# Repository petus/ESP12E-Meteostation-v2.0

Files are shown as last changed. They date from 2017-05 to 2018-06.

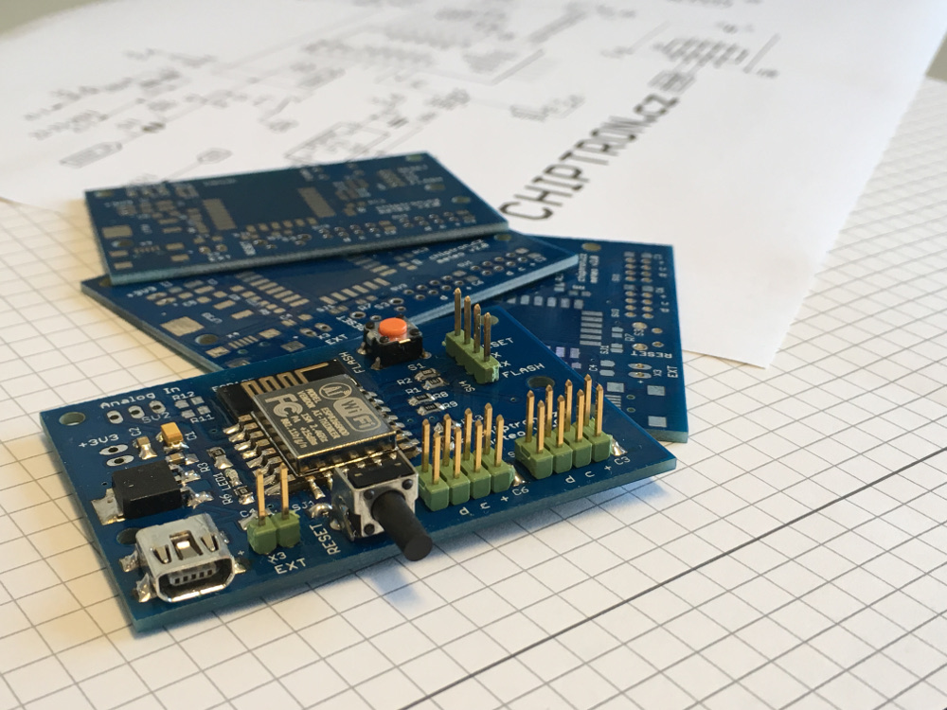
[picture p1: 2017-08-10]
meteo_v2.JPG

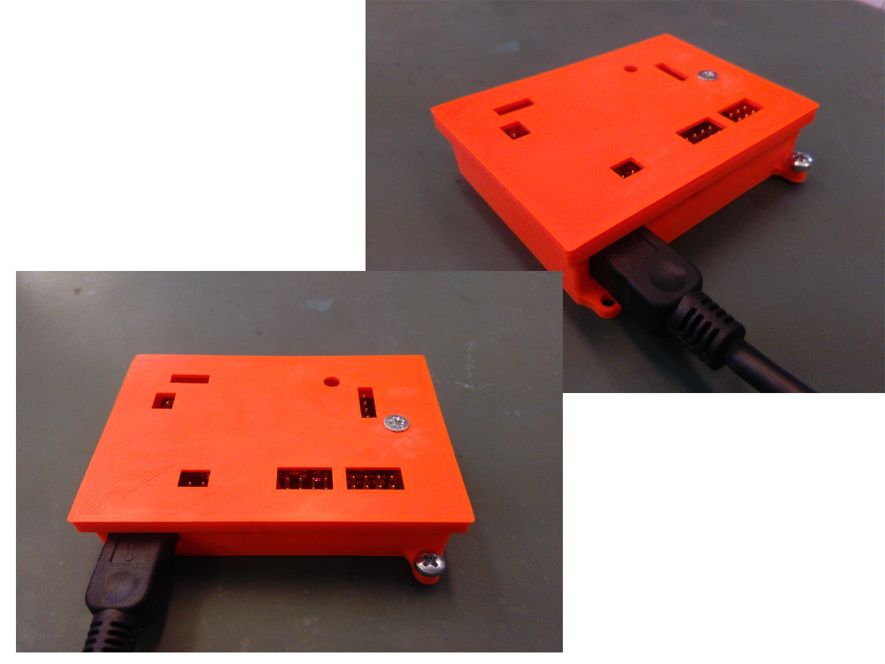
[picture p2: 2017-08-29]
3Dcase/meteo_v2_3Dcase.jpg

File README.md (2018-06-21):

# ESP12E-Meteostation-v2.0<br>
<br>
<b>The meteostation building kit is available on http://kitman.eprodavac.cz/meteostanice-chiptron-meteov2-wifi-79/</b><br>
<br>
(english language) https://time4ee.com, https://time4ee.com/articles.php?article_id=48 <br>
(czech language) https://chiptron.cz, https://chiptron.cz/articles.php?article_id=175 <br>
<br>
<strong>List of interesting sensors:</strong> <br>
(english) https://time4ee.com/articles.php?article_id=58 <br>
(czech) https://chiptron.cz/articles.php?article_id=127 <br>
<br>
Mini meteostation with ESP12E (ESP8266, NodeMCU)<br>

Mini meteostation contains 4x 4pin headers for I2C sensors and one analog header for connecting of analog sensor like CO2 sensor.<br>

PCB is designed in eagle.<br>
The platic box is KM-27 and 3D case is available in this repository.<br>
<br>
<strong>How to upload the code:</strong><br>
Meteo board | USB-UART bridge<br>
RESET -> DTR<br>
TX -> RX<br>
RX -> TX<br>
FLASH -> GND<br>
<br>
Choose NodeMCU 1.0 board in Board manager, upload the code. Then unplug the USB-UART converter<br>
<br>
<strong>Connecting of I2C sensor:</strong><br>
Meteo board | I2C sensor<br>
\+ -> VCC (3.3V)<br>
c -> SCL<br>
d -> SDA<br>
no label -> GND<br>
<br>
And power supply of course.<br>
<br>
The meteo board can be powered by mini USB connector, 3.3V pin header or external power supply (up to 16V)<br>
<br>
If you want to use sleeping mode of the ESP12E, solder SJ1 jumper (GPIO16 and RESET pin)

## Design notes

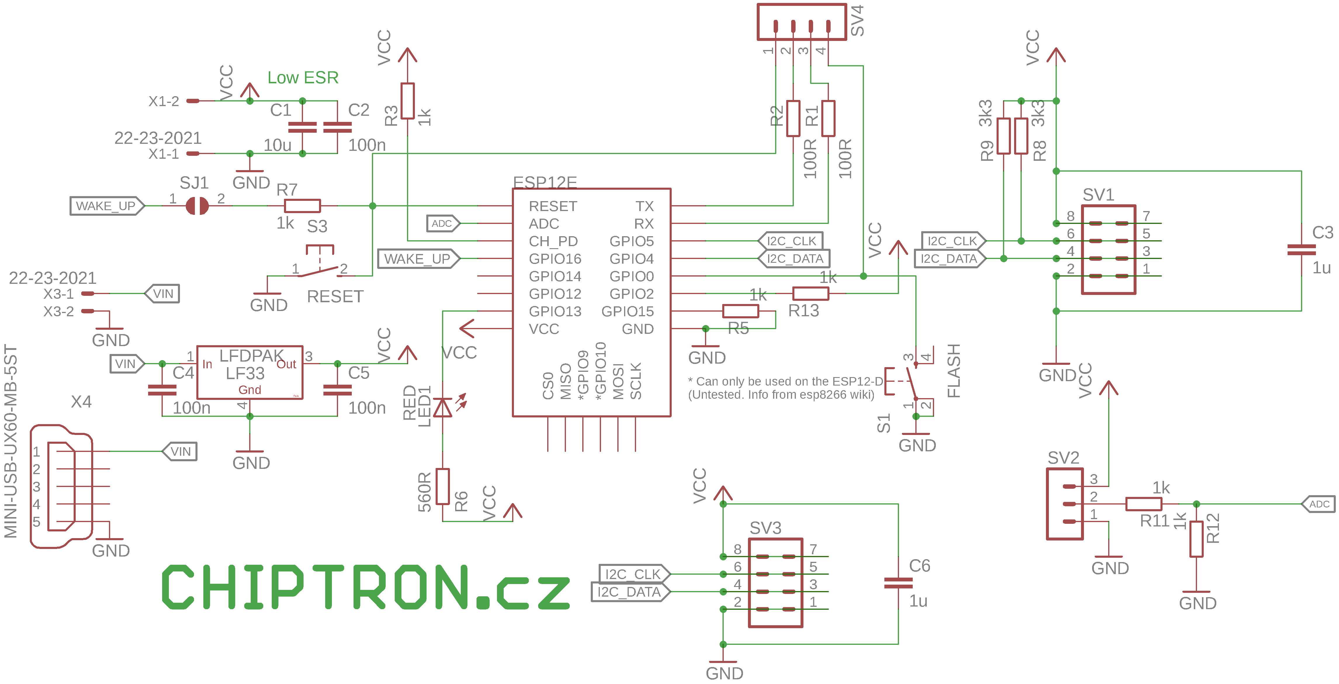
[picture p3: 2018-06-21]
PCB/MeteoV2_WiFI_schematic.png

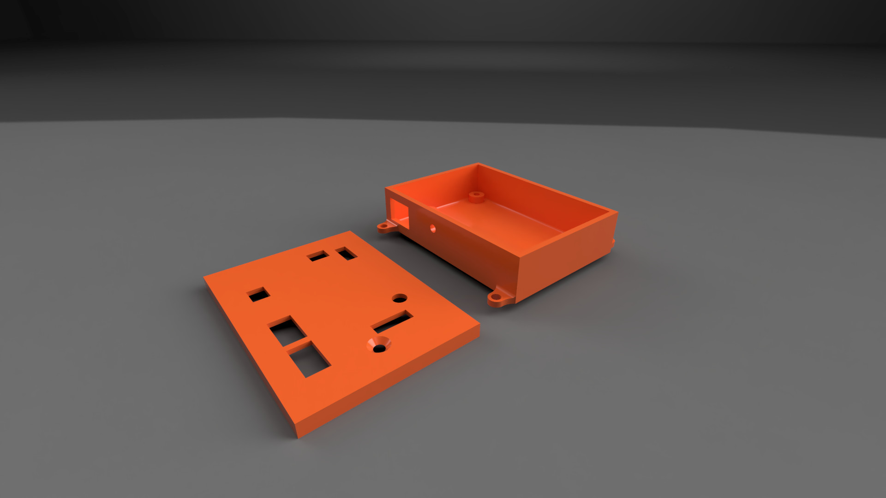
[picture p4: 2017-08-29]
3Dcase/Meteo_BOX_v10.jpg

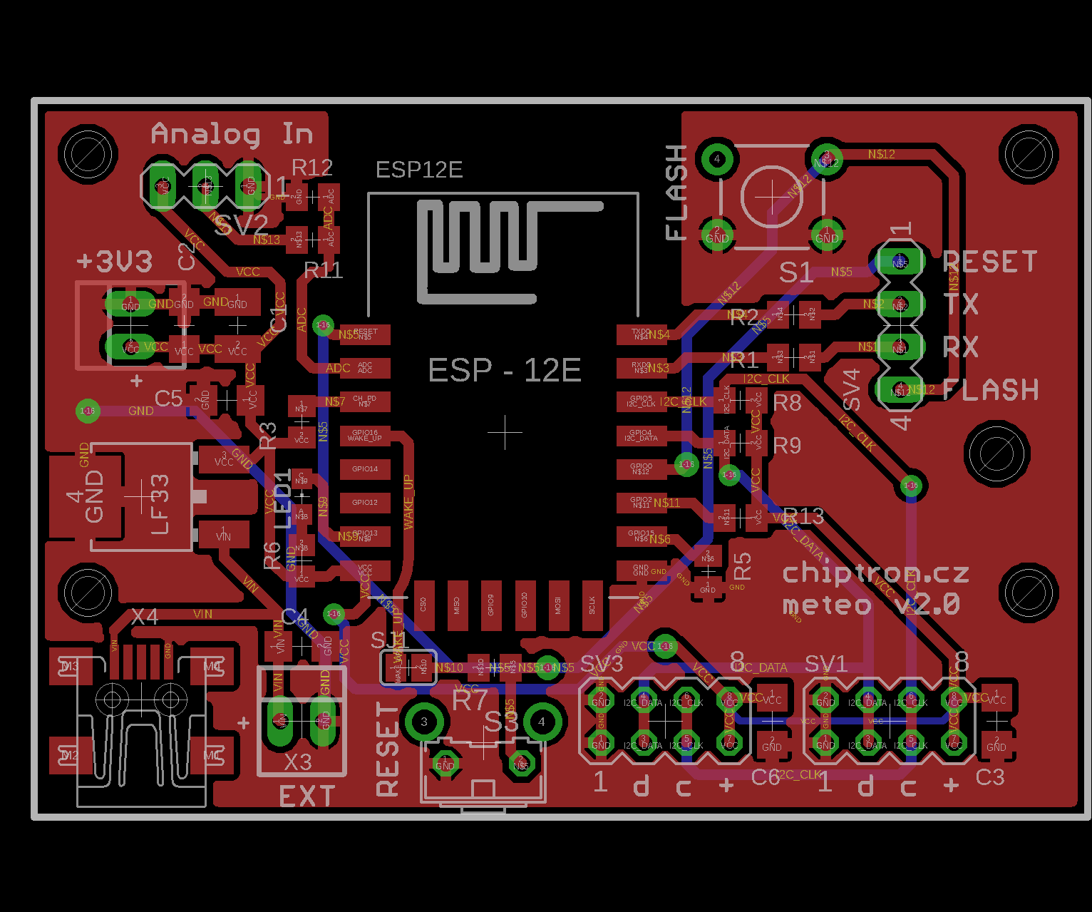
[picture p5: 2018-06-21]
PCB/MeteoV2_WiFI_PCB.png

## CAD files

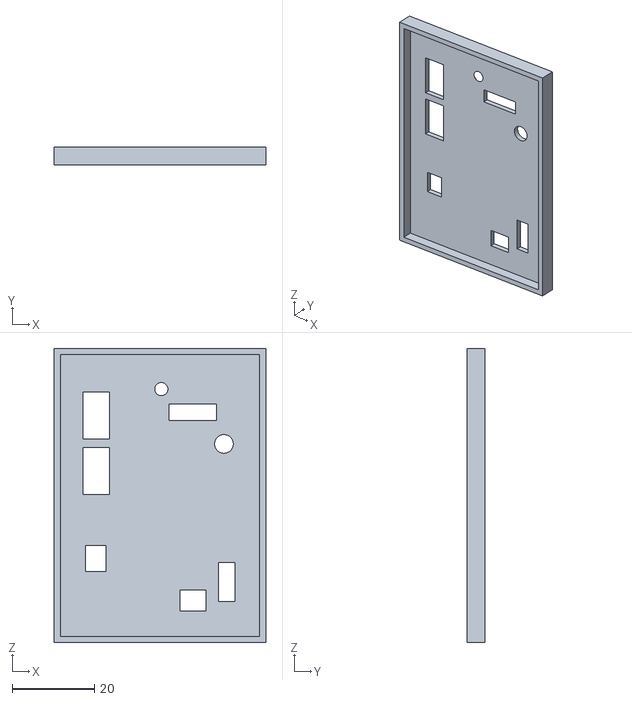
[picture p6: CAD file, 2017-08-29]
3Dcase/MeteoBox_TOP.stl
51.5 x 4.50 x 71.5

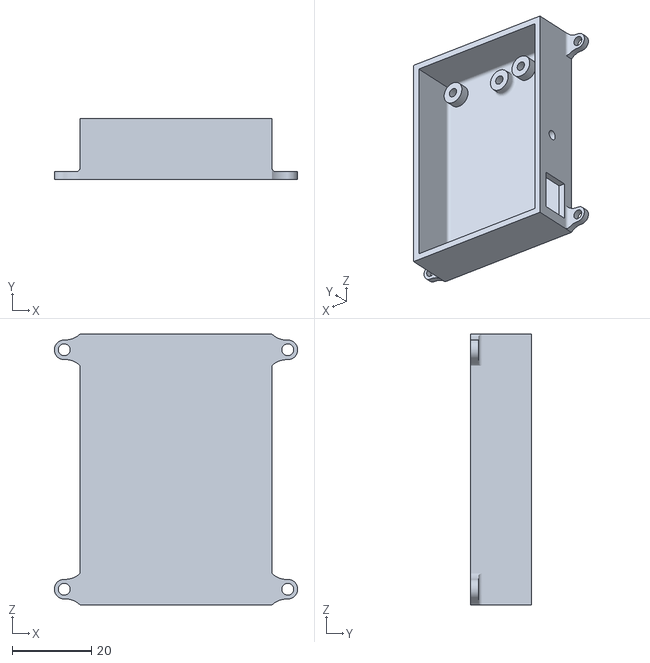
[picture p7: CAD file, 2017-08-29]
3Dcase/MeteoBox_BOT.stl
61.5 x 15.5 x 68.5

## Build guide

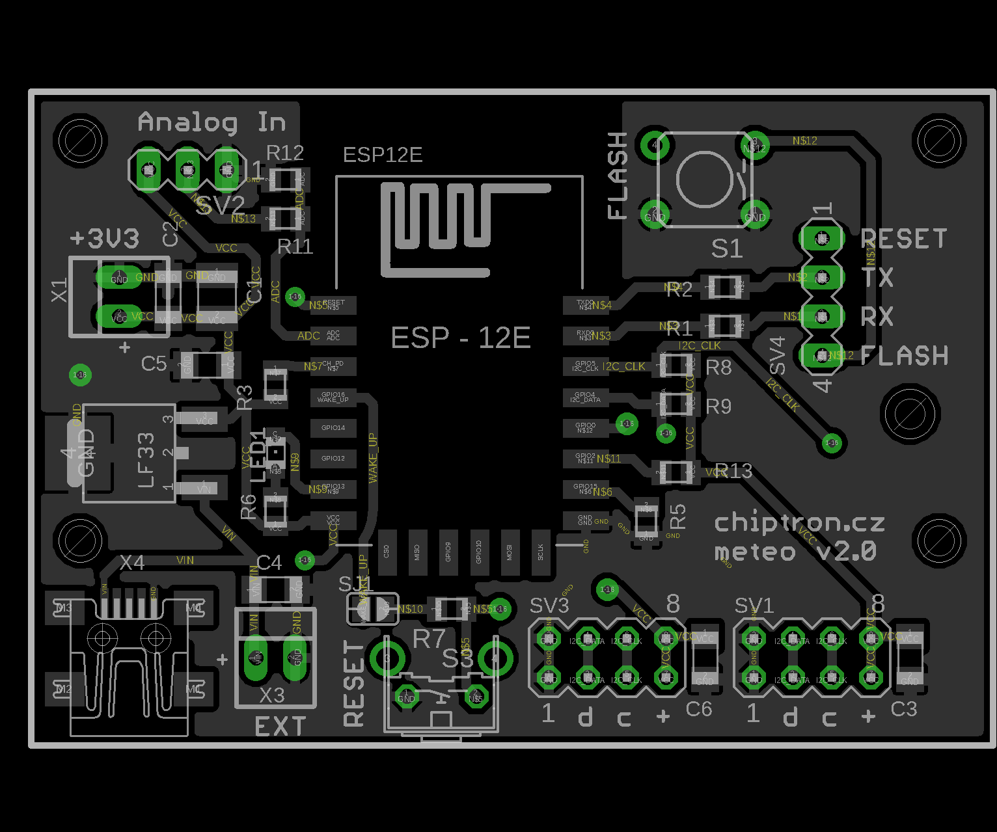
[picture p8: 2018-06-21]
PCB/MeteoV2_WiFI_assembly.png

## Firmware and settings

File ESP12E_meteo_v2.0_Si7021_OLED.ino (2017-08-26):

/**
 * NodeMCU (ESP12E) + Si7021 + 128x64px OLED
 *
 * made by Petus (2017)
 * https://chiptron.cz/articles.php?article_id=113
 * https://time4ee.com/articles.php?article_id=48
 *
 * Si7021 library - https://github.com/LowPowerLab/SI7021
 * 128x64px OLED display - http://www.adafruit.com/category/63_98
 * Add to Arduino IDE "Adafruit GFX Library" and "Adafruit SSD1306" library
 */

#include <ESP8266WiFi.h>
#include <Wire.h>
#include <SI7021.h>
#include <Adafruit_GFX.h>
#include <Adafruit_SSD1306.h>

#define SDA 4 // GPIO4 on D2
#define SCL 5 // GPIO5 on D1

#define OLED_RESET 19 //choose unused pin, connect the RESET pin to VCC (3.3V)
Adafruit_SSD1306 display(OLED_RESET);

SI7021 sensor;

void setup() {
  
  Serial.begin(9600); // Open serial connection to report values to host
  delay(10);

  sensor.begin(SDA,SCL);

  // by default, we'll generate the high voltage from the 3.3v line internally! (neat!)
  display.begin(SSD1306_SWITCHCAPVCC, 0x3C);  // initialize with the I2C addr 0x3D (for the 128x64)

  delay(2000);
  display.clearDisplay();

  // text display tests
  display.setTextSize(1);
  display.setTextColor(WHITE);
  display.setCursor(0,0);
  display.println("chiptron.cz");
  display.setCursor(0,10);
  display.println("time4ee.com");
  display.setCursor(0,20);
  display.println("Meteostation board");
  display.display();
  delay(2000);
  display.clearDisplay();

  display.setTextSize(2);

}


void loop() {
  int temperature = sensor.getCelsiusHundredths();
  unsigned int humidity = sensor.getHumidityPercent();

  Serial.println("Temperature: ");
  Serial.print(String(temperature/100.0, 2));
  Serial.println(" °C");
  Serial.println("Humidity: ");
  Serial.println(humidity);

  display.clearDisplay();
  display.setCursor(0, 0);
  display.print(String(temperature/100.0, 2));
  display.println(" 'C");
  display.setCursor(0, 15);
  display.print(humidity);
  display.println(" %");
  display.display();
  
  delay(10000);
  
}

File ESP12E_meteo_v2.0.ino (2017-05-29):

/**
 * NodeMCU (ESP12E) + Si7021 = Meteostation
 *
 * made by Petus
 * http://petus.cz
 * http://chiptron.cz
 * http://time4ee.com
 *
 * Si7021 library - https://github.com/LowPowerLab/SI7021
 * 
 */

#include <ESP8266WiFi.h>
#include <Wire.h>
#include <SI7021.h>

#define SDA 4 // GPIO4 on D2
#define SCL 5 // GPIO5 on D1

#define ARDUINO_ARCH_ESP8266

#define SLEEP_DELAY_IN_SECONDS  30

const char* ssid     = "SSID";
const char* password = "PASSWORD";

const char* host = "HostName.tmep.cz";

SI7021 sensor;

void setup() {
  unsigned int numberOfConnections= 0;
  
  Serial.begin(9600); // Open serial connection to report values to host
  delay(10);
   
  Serial.println();
  Serial.println();

  Serial.print("Meteostation by Petus\n");
  Serial.print("http://chiptron.cz\n");
  Serial.print("http://time4ee.com\n");
  Serial.println("FW version: 1.2\n");
  
  Serial.print("Connecting to ");
  Serial.println(ssid);
  
  WiFi.begin(ssid, password);
  
  while (WiFi.status() != WL_CONNECTED) {
    delay(500);
    Serial.print(".");
    numberOfConnections++;

    Serial.println("Number Of Connections:");
    Serial.println(numberOfConnections);

    // if ESP12E can't connect to WiFi -> enable deep.sleep
    if (numberOfConnections > 10)
    {
        //if you want to use deep sleep, connect RST with D0 (GPIO16)
        //ESP.deepSleep(SLEEP_DELAY_IN_SECONDS * 1000000, WAKE_RF_DEFAULT);
        delay(1000);
        return;
    }
  }

  Serial.println("");
  Serial.println("WiFi connected");  
  Serial.println("IP address: ");
  Serial.println(WiFi.localIP());
  sensor.begin(SDA,SCL);

}


void loop() {
  int temperature = sensor.getCelsiusHundredths();
  unsigned int humidity = sensor.getHumidityPercent();

  Serial.print("connecting to ");
  Serial.println(host);
  // Use WiFiClient class to create TCP connections
  WiFiClient client;
  const int httpPort = 80;
  if (!client.connect(host, httpPort)) 
  {
    Serial.println("connection failed");
    return;
  }

    // We now create a URI for the request
  String url = "/index.php?";

  Serial.print("Requesting URL: ");
  Serial.println(url);

  //temperatureH = String(temperature/100.0, 2);

  // This will send the request to the server
    client.print(String("GET ") + url + "tempC=" + String(temperature/100.0, 2) + "&humV=" + humidity + " HTTP/1.1\r\n" +
             "Host: " + host + "\r\n" + 
             "Connection: close\r\n\r\n");

  delay(10);

  // Read all the lines of the reply from server and print them to Serial
  Serial.println("Respond:");
  while(client.available())
  {
    String line = client.readStringUntil('\r');
    Serial.print(line);
  }

  Serial.println();
  Serial.println("closing connection");

  //if you want to use deep sleep, connect RST with D0 (GPIO16)
  //ESP.deepSleep(SLEEP_DELAY_IN_SECONDS * 1000000, WAKE_RF_DEFAULT);
  delay(10000);
  
}
